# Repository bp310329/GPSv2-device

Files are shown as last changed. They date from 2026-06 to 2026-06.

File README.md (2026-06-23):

# GPSv2-device
Program of embedded device. This is project of GPS device with sipmle navigation. This device allows for real-time GPS tracking and uploading location data to data base via GSM network, and presentation of this data on the map on website. Second application is simple navigation through points placed on the map.
[WIP]

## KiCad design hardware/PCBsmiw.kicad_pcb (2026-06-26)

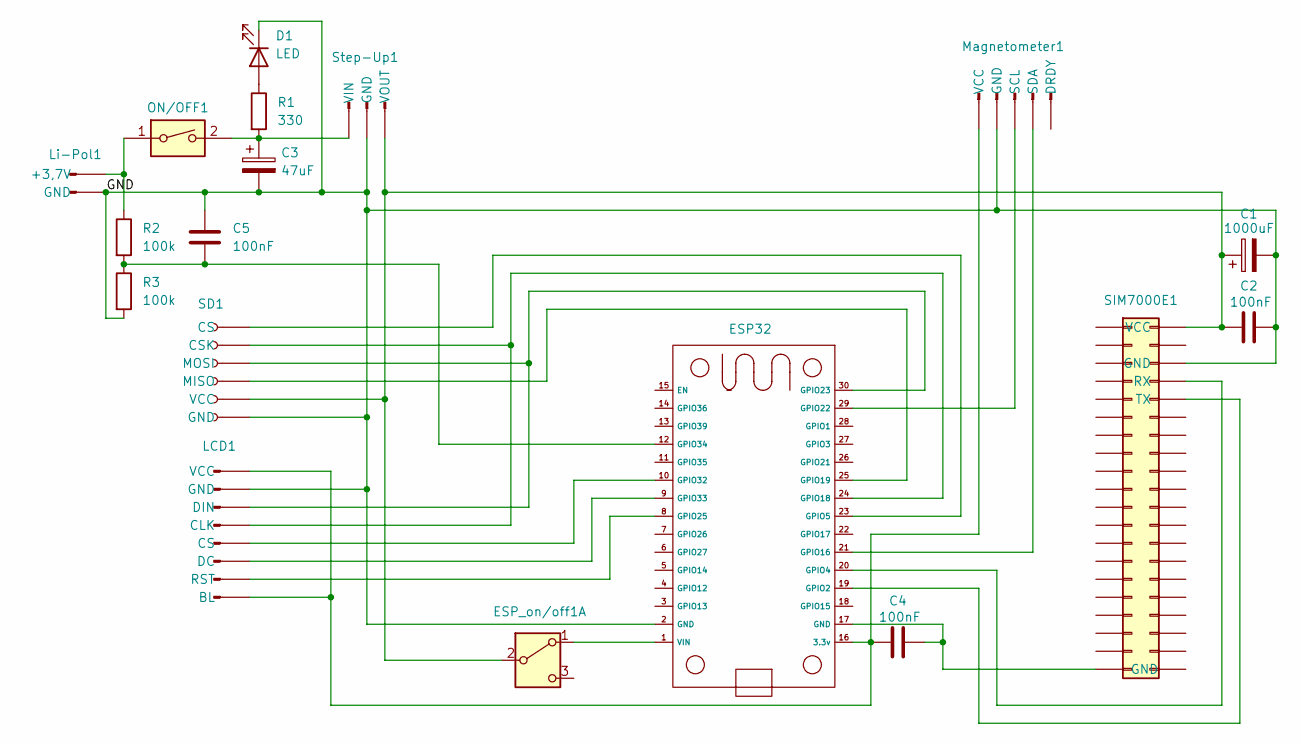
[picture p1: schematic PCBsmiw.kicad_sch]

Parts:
C1: 1000uF; CP_Radial_D10.0mm_P5.00mm
C2, C4, C5: 100nF; C_Disc_D3.8mm_W2.6mm_P2.50mm
C3: 47uF; CP_Radial_D5.0mm_P2.00mm
D1: LED; LED_D3.0mm
ESP32: ESP32_30pin
ESP_on/off1: SW_DPDT_x2; SW_CK_JS202011CQN_DPDT_Straight
LCD1: Conn_01x08_Pin; PinSocket_1x08_P2.54mm_Vertical
Li-Pol1: Conn_01x02_Pin; PinHeader_1x02_P2.54mm_Horizontal
Magnetometer1: Conn_01x05_Pin; PinHeader_1x05_P2.54mm_Vertical
ON/OFF1: SW_DIP_x01; SW_DIP_SPSTx01_Slide_9.78x4.72mm_W7.62mm_P2.54mm
R1: 330; R_Axial_DIN0207_L6.3mm_D2.5mm_P7.62mm_Horizontal
R2, R3: 100k; R_Axial_DIN0207_L6.3mm_D2.5mm_P7.62mm_Horizontal
SD1: Conn_01x06_Socket; PinSocket_1x06_P2.54mm_Horizontal
SIM7000E1: Conn_02x20_Odd_Even; PinHeader_2x20_P2.54mm_Vertical
Step-Up1: Conn_01x03_Pin; PinHeader_1x03_P2.54mm_Vertical

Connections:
/GND: C1.2, C2.2, C3.2, C5.1, D1.1 (K), ESP32.2 (GND), LCD1.2 (GND), Li-Pol1.2 (GND), Magnetometer1.2 (GND), R3.2, SD1.6 (GND), SIM7000E1.6 (GND), Step-Up1.2 (GND)
unnamed: C4.2, ESP32.17 (GND), SIM7000E1.39 (GND)
unnamed: D1.2 (A), R1.1
unnamed: C4.1, ESP32.16 (3.3v), LCD1.1 (VCC), LCD1.8 (BL), Magnetometer1.1 (VCC)
unnamed: ESP32.19 (GPIO2), SIM7000E1.10 (TX)
unnamed: ESP32.20 (GPIO4), SIM7000E1.8 (RX)
unnamed: ESP32.23 (GPIO5), SD1.1 (CS)
unnamed: ESP32.21 (GPIO16), Magnetometer1.4 (SDA)
unnamed: ESP32.24 (GPIO18), LCD1.4 (CLK), SD1.2 (CSK)
unnamed: ESP32.25 (GPIO19), SD1.4 (MISO)
unnamed: ESP32.29 (GPIO22), Magnetometer1.3 (SCL)
unnamed: ESP32.30 (GPIO23), LCD1.3 (DIN), SD1.3 (MOSI)
unnamed: ESP32.8 (GPIO25), LCD1.7 (RST)
unnamed: ESP32.10 (GPIO32), LCD1.5 (CS)
unnamed: ESP32.9 (GPIO33), LCD1.6 (DC)
unnamed: C5.2, ESP32.12 (GPIO34), R2.2, R3.1
unnamed: ESP32.1 (VIN), ESP_on/off1.1 (A)
unnamed: C1.1, C2.1, ESP_on/off1.2 (B), SD1.5 (VCC), SIM7000E1.2 (VCC), Step-Up1.1 (VOUT)
unnamed: Li-Pol1.1 (+3,7V), ON/OFF1.1, R2.1
unnamed: C3.1, ON/OFF1.2, R1.2, Step-Up1.3 (VIN)

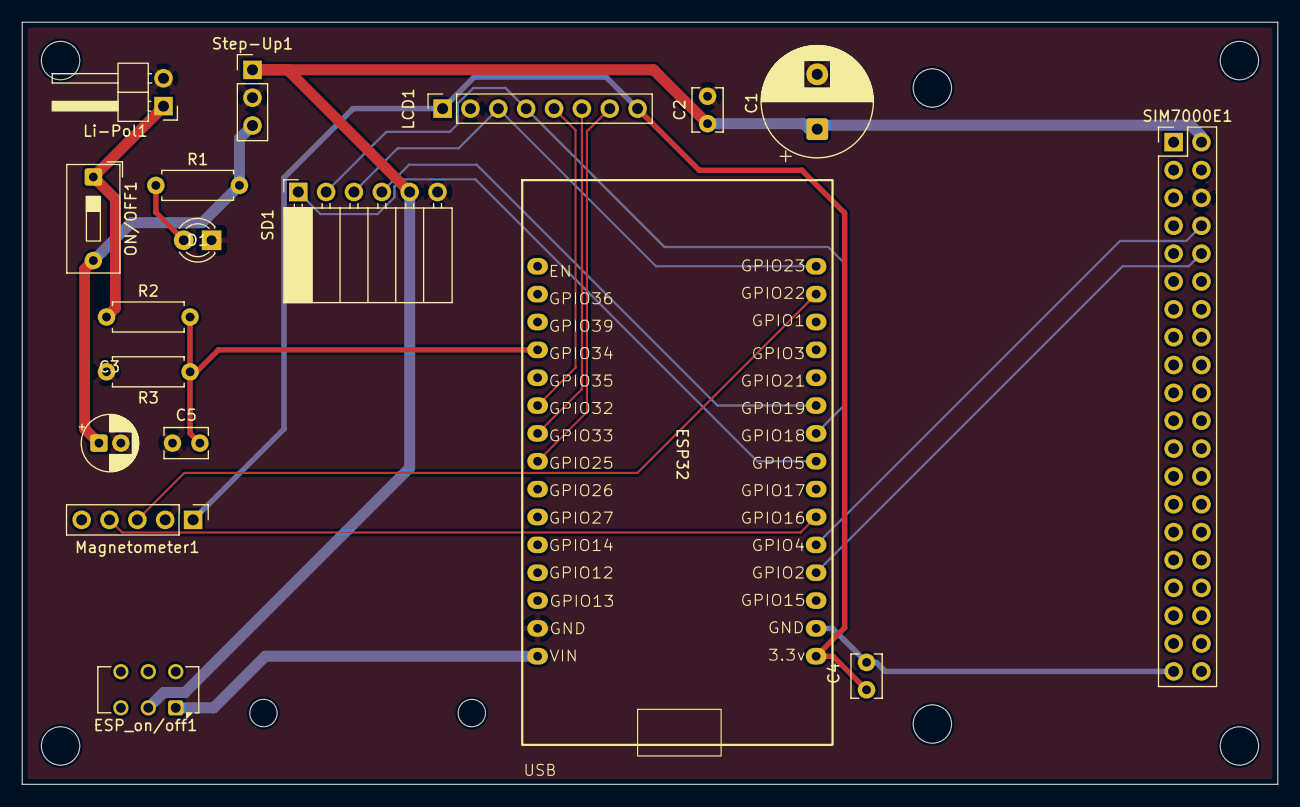
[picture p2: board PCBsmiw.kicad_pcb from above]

Board: 2 copper layers, 114.5 x 69.5 mm, 18 parts (0 on the bottom side), 20 nets.

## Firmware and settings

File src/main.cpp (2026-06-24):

#include <Arduino.h>
#include <Wire.h>
#include <SPI.h>
#include <Adafruit_GFX.h>
#include <Adafruit_ILI9341.h>
#include <Adafruit_QMC5883P.h>
#include <DFRobot_SIM7000.h>
#include <SdFat.h>
#include <ArduinoJson.h>
#include <math.h>

#define TFT_CS 32
#define TFT_DC 33
#define TFT_RST 25
#define MAG_SDA 16
#define MAG_SCL 22
#define SIM_TX 4
#define SIM_RX 2
#define SD_CS 5

struct Waypoint {
  float lat;
  float lon;
  bool visited;
};

Adafruit_ILI9341 tft = Adafruit_ILI9341(TFT_CS, TFT_DC, TFT_RST);
Adafruit_QMC5883P mag = Adafruit_QMC5883P();
DFRobot_SIM7000 sim7000(&Serial2);
SdFat SD;

Waypoint* waypoints = nullptr;
int currentTargetIndex = -1;

int posX = 10, posY = 10;
uint32_t loopTimer = 0, screenTimer = 0, transmisionTimer = 0;
bool APNStatus = false, connected = false;
byte mode = 0;
String currentTime, latitude, longitude;
float azimuth;
int gpsErrorCounter = 0;
float distanceToTarget = 0.0;
int arrowAngle = 0;

int savedCount = 0, totalWaypoints = 0;
int ok = 0, error = 0;

const int MAX_GPS_ERRORS = 6;
const char* DEVICE_ID = "tracker01";
const char* OFFLINE_FILE = "offlineData.txt";
const char* NAVI_FILE = "naviData.txt";
const char* SERVER = "http://frog03.mikr.us:21491/api/device/telemetry";
const char* MODE_URL = "http://frog03.mikr.us:21491/api/device/mode";
const char* WAYPOINTS_URL = "http://frog03.mikr.us:21491/api/device/pending-waypoints";

bool wait(uint32_t &lastTime, uint32_t interval);
void printLine(const String text, int &posX, int &posY, uint16_t color = ILI9341_WHITE, int textSize = 1);
void replaceLine(const String text, int &posX, int &posY, uint16_t color = ILI9341_WHITE, int textSize = 1);
void updateScreen();
bool initializeSIM7000();
bool initializeSIMCard();
bool initializeNetwork();
bool configureAPN();
bool initializeGPS();
bool waitForGPS();
String getTime();
void handleTransmission();
void saveToSD(String json);
void processOfflineDataBatch();
float calculateDistance(float lat1, float lon1, float lat2, float lon2);
float calculateBearing(float lat1, float lon1, float lat2, float lon2);
void findNextClosestWaypoint(float currentLat, float currentLon);
void drawNavigationArrow(int cx, int cy, int angle, uint16_t arrowColor);
float getAzimuth();

void setup() {
  Serial.begin(115200);
  Serial2.begin(115200, SERIAL_8N1, SIM_RX, SIM_TX);
  Wire.begin(MAG_SDA, MAG_SCL);

  Serial.println("MCU starting...");

  if (!mag.begin()) {
    Serial.println("Magnetometer has not been found!");
    while (1) {
      delay(10);
    }
  } else {
    Serial.println("Magnetometer OK");
  }

  mag.setMode(QMC5883P_MODE_NORMAL);
  mag.setODR(QMC5883P_ODR_50HZ);

  tft.begin();
  tft.setRotation(1);
  tft.fillScreen(ILI9341_BLACK);

  if (!SD.begin(SD_CS, SD_SCK_MHZ(4))) {
    Serial.println("SD Card Mount Failed!");
  } else {
    Serial.println("SD Card Initialized.");
  }
  SD.remove(OFFLINE_FILE);

  initializeSIM7000();
  initializeSIMCard();
  initializeNetwork();
  delay(5000);
  configureAPN();
  initializeGPS();

  delay(1000);
  posY = 10;
  waitForGPS();
  tft.fillScreen(ILI9341_BLACK);

  // =========================================================================
  // --- SPRAWDZANIE TRYBU I POBIERANIE WSPÓŁRZĘDNYCH ---
  // =========================================================================
  int setupX = 10, setupY = 10;

  printLine("Waiting for server...", setupX, setupY, ILI9341_WHITE, 2);
  
  String modeResponse = "";

  sim7000.httpGet(MODE_URL);
  
  while(Serial2.available()) Serial2.read();
  
  Serial2.print("AT+HTTPPARA=\"URL\",\"");
  Serial2.print(MODE_URL);
  Serial2.println("\"");
  delay(200);
  
  Serial2.println("AT+HTTPACTION=0");
  
  unsigned long start = millis();
  bool actionOk = false;
  while(millis() - start < 6000) {
    if(Serial2.available()) {
      String line = Serial2.readStringUntil('\n');
      if(line.indexOf("+HTTPACTION: 0,200") != -1) {
        actionOk = true;
        break;
      }
    }
    delay(10);
  }
  
  if(actionOk) {
    Serial2.println("AT+HTTPREAD");
    delay(500);
    while(Serial2.available()) {
      modeResponse += (char)Serial2.read();
    }
  }

  if (modeResponse.indexOf("\"mode\":\"planning\"") != -1) {
    mode = 1;
    replaceLine("MODE: NAVIGATION", setupX, setupY, ILI9341_YELLOW, 2);
    printLine("Downloading waypoints...", setupX, setupY, ILI9341_WHITE, 2);
    
    SD.remove(NAVI_FILE);
    FsFile naviFile = SD.open(NAVI_FILE, O_RDWR | O_CREAT | O_APPEND);
    
    if (!naviFile) {
      printLine("SD Write Error!", setupX, setupY, ILI9341_RED, 2);
      mode = 0;
      return;
    }

    bool morePointsAvailable = true;

    while (morePointsAvailable) {
      while(Serial2.available()) Serial2.read();
      
      Serial2.print("AT+HTTPPARA=\"URL\",\"");
      Serial2.print(WAYPOINTS_URL);
      Serial2.println("\"");
      delay(200);
      
      Serial2.println("AT+HTTPACTION=0");
      
      unsigned long startWp = millis();
      bool wpActionOk = false;
      
      while(millis() - startWp < 8000) {
        if(Serial2.available()) {
          String line = Serial2.readStringUntil('\n');
          
          if(line.indexOf("+HTTPACTION:") != -1) {
            if(line.indexOf("0,200") != -1) {
              wpActionOk = true;
            } else {
              Serial.print("MODEM RETURNED ERROR STATE: ");
              Serial.println(line);
            }
            break;
          }
        }
        delay(10);
      }
      
      if(!wpActionOk) {
        Serial.println("Pętla zatrzymana: Brak statusu HTTP 200.");
        morePointsAvailable = false;
        break;
      }
      
      Serial2.println("AT+HTTPREAD");
      
      String wpResponse = "";
      unsigned long lastCharTime = millis();
      while (millis() - lastCharTime < 1000) {
        while (Serial2.available()) {
          char c = (char)Serial2.read();
          wpResponse += c;
          lastCharTime = millis();
        }
        delay(5);
      }
      
      int pointsIdx = wpResponse.indexOf("\"points\":[");
      if (pointsIdx != -1) {
        pointsIdx += 10;
        int batchSaved = 0;
        
        while (true) {
          int latIndex = wpResponse.indexOf("\"lat\":", pointsIdx);
          if (latIndex == -1) break;
          int latEnd = wpResponse.indexOf(",", latIndex);
          String latVal = wpResponse.substring(latIndex + 6, latEnd);
          
          int lngIndex = wpResponse.indexOf("\"lng\":", latEnd);
          if (lngIndex == -1) break;
          int lngEnd = wpResponse.indexOf("}", lngIndex);
          String lngVal = wpResponse.substring(lngIndex + 6, lngEnd);
          
          naviFile.println(latVal + "," + lngVal);
          savedCount++;
          batchSaved++;
          
          pointsIdx = lngEnd;
        }
        
        if (batchSaved == 0) {
          morePointsAvailable = false;
        }
        
        Serial.print("Pomyślnie zapisano partię ");
        Serial.print(batchSaved);
        Serial.println(" punktów.");
        
      } else {
          morePointsAvailable = false;
      }
      
      delay(1500); 
    }
    
    naviFile.close();
    
    if (savedCount > 0) {
      totalWaypoints = savedCount;

      printLine("Saved " + String(savedCount) + " points!", setupX, setupY, ILI9341_GREEN, 2);
      waypoints = new Waypoint[totalWaypoints];
      
      // 2. Otwarcie pliku ponownie - tym razem tylko DO ODCZYTU
      FsFile readFile = SD.open(NAVI_FILE, O_RDONLY);
      if (readFile) {
        int idx = 0;
        
        while (readFile.available() && idx < totalWaypoints) {
          String line = readFile.readStringUntil('\n');
          line.trim();
          
          int commaIdx = line.indexOf(',');
          if (commaIdx != -1) {
            String latStr = line.substring(0, commaIdx);
            String lonStr = line.substring(commaIdx + 1);
            
            waypoints[idx].lat = latStr.toFloat();
            waypoints[idx].lon = lonStr.toFloat();
            waypoints[idx].visited = false;
            
            idx++;
          }
        }
        readFile.close();
        
        Serial.print("[NAVI] Pomyślnie załadowano do RAM: ");
        Serial.print(idx);
        Serial.println(" punktów trasy.");
      } else {
        Serial.println("[CRITICAL] Nie udało się otworzyć pliku nawigacji do odczytu!");
        mode = 0;
      }
      
    } else {
      printLine("No active route found.", setupX, setupY, ILI9341_WHITE, 2);
      mode = 0;
    }
    delay(2000);
    
  } else {
    mode = 0;
  }

  tft.fillScreen(ILI9341_BLACK);
}

void loop() {
  switch (mode) {
    case 0:
      if (wait(loopTimer, 500)) {
        bool gotPosition = sim7000.getPosition();
        
        if (gotPosition) {
          latitude = sim7000.getLatitude();
          longitude = sim7000.getLongitude();
        } else {
          gpsErrorCounter++;
          
          if (gpsErrorCounter >= MAX_GPS_ERRORS) {
            waitForGPS();
            gpsErrorCounter = 0;
          }
        }
      }

      if (wait(screenTimer, 500)) {
        azimuth = getAzimuth();

        arrowAngle = (int)(round(azimuth / 15.0) * 15.0);
        if (arrowAngle >= 360) arrowAngle -= 360;
        updateScreen();
      }

      if (wait(transmisionTimer, 10000)) {
        handleTransmission();
      }
      
      break;

    case 1:
      if (wait(loopTimer, 500)) {
        bool gotPosition = sim7000.getPosition();
        
        if (gotPosition) {
          latitude = sim7000.getLatitude();
          longitude = sim7000.getLongitude();

          float tempLat = latitude.toFloat();
          float tempLon = longitude.toFloat();
          azimuth = getAzimuth();

          if (currentTargetIndex == -1) {
            findNextClosestWaypoint(tempLat, tempLon);
          }

          if (currentTargetIndex != -1) {
            distanceToTarget = calculateDistance(tempLat, tempLon, waypoints[currentTargetIndex].lat, waypoints[currentTargetIndex].lon);

            if (distanceToTarget <= 25.0) {
              Serial.print("PUNKT ZDOBYTY! Indeks: "); Serial.println(currentTargetIndex);
              waypoints[currentTargetIndex].visited = true;
              
              findNextClosestWaypoint(tempLat, tempLon);
            }

            if (currentTargetIndex != -1) {
              float bearingToTarget = calculateBearing(tempLat, tempLon, waypoints[currentTargetIndex].lat, waypoints[currentTargetIndex].lon);
              
              float relativeAngle = bearingToTarget - azimuth;
              if (relativeAngle < 0) relativeAngle += 360.0;

              arrowAngle = (int)(round(relativeAngle / 15.0) * 15.0);
              if (arrowAngle >= 360) arrowAngle -= 360;
            }
          } else {
            Serial.println("Wszystkie punkty zostały zdobyte! Koniec podróży.");
            arrowAngle = 0;
            distanceToTarget = 0.0;
            mode = 0;
          }

        } else {
          gpsErrorCounter++;
          if (gpsErrorCounter >= MAX_GPS_ERRORS) {
            waitForGPS();
            gpsErrorCounter = 0;
          }
        }
      }

      if (wait(screenTimer, 500)) {
        updateScreen();
      }

      break;
  }
}

bool wait(uint32_t &lastTime, uint32_t interval) {
  uint32_t current = millis();
  if (current - lastTime >= interval) {
    lastTime = current;
    return true;
  }
  return false;
}

void printLine(const String text, int &posX, int &posY, uint16_t color, int textSize) {
  tft.setCursor(posX, posY);
  tft.setTextColor(color);
  tft.setTextSize(textSize);
  tft.fillRect(posX, posY, 120, textSize * 10, ILI9341_BLACK);
  tft.println(text);
  posY += textSize * 10;
}

void replaceLine(const String text, int &posX, int &posY, uint16_t color, int textSize) {
  tft.fillRect(posX, posY - textSize * 10, tft.width() - posX * 2, textSize * 10, ILI9341_BLACK);
  int originalPosY = posY - textSize * 10;
  printLine(text, posX, originalPosY, color, textSize);
}

void updateScreen() {
  posY = 10;

  if (mode == 0) {
    printLine("MODE: TRACKER", posX, posY, ILI9341_YELLOW, 2);
  } else if (mode == 1) {
    printLine("MODE: NAVIGATION", posX, posY, ILI9341_YELLOW, 2);
  }

  if (connected) {
    printLine("ONLINE", posX, posY, ILI9341_GREEN, 2);
  } else {
    printLine("OFFLINE", posX, posY, ILI9341_RED, 2);
  }
  printLine(latitude, posX, posY, ILI9341_WHITE, 2);
  printLine(longitude, posX, posY, ILI9341_WHITE, 2);
  printLine(String(azimuth), posX, posY, ILI9341_WHITE, 2);

  if (mode == 0) {
    printLine(String(ok) + "/" + String(error), posX, posY, ILI9341_WHITE, 2);
  } else if (mode == 1) {
    printLine("Ang: " + String(arrowAngle), posX, posY, ILI9341_WHITE, 2);
  }

  drawNavigationArrow(230, 120, arrowAngle, ILI9341_RED);

  posY = 222;
  printLine(currentTime, posX, posY, ILI9341_WHITE, 1);
}

bool initializeSIM7000() {
  printLine("Initializing SIM7000...", posX, posY, ILI9341_WHITE, 2);

  if (sim7000.isON()) {
    printLine("OK", posX, posY, ILI9341_GREEN, 2);
    return true;
  } else {
    printLine("ERROR", posX, posY, ILI9341_RED, 2);

    while (!sim7000.isON()) {
      delay(500);
    }

    replaceLine("OK", posX, posY, ILI9341_GREEN, 2);
    return true;
  }
}

bool initializeSIMCard() {
  printLine("Checking SIM card...", posX, posY, ILI9341_WHITE, 2);

  if (sim7000.checkSIMStatus()) {
    printLine("OK", posX, posY, ILI9341_GREEN, 2);
    return true;
  } else {
    printLine("ERROR", posX, posY, ILI9341_RED, 2);

    while (!sim7000.checkSIMStatus()) {
      delay(500);
    }

    replaceLine("OK", posX, posY, ILI9341_GREEN, 2);
    return true;
  }
}

bool initializeNetwork() {
  printLine("Setting network mode...", posX, posY, ILI9341_WHITE, 2);

  if (sim7000.setNetMode(sim7000.eGPRS)) {
    printLine("OK", posX, posY, ILI9341_GREEN, 2);
    return true;
  } else {
    printLine("ERROR", posX, posY, ILI9341_RED, 2);

    while (!sim7000.setNetMode(sim7000.eGPRS)) {
      delay(500);
    }

    replaceLine("OK", posX, posY, ILI9341_GREEN, 2);
    return true;
  }
}

bool configureAPN() {
  printLine("Configuring APN...", posX, posY, ILI9341_WHITE, 2);

  if (sim7000.httpInit(sim7000.eGPRS, APNStatus)) {
    printLine("OK", posX, posY, ILI9341_GREEN, 2);
    return true;
  } else {
    printLine("ERROR", posX, posY, ILI9341_RED, 2);

    while (!sim7000.httpInit(sim7000.eGPRS, APNStatus)) {
      delay(500);
    }

    replaceLine("OK", posX, posY, ILI9341_GREEN, 2);
    return true;
  }
}

bool initializeGPS() {
  printLine("Initializing GPS...", posX, posY, ILI9341_WHITE, 2);

  if (sim7000.initPos()) {
    printLine("OK", posX, posY, ILI9341_GREEN, 2);
    return true;
  } else {
    printLine("ERROR", posX, posY, ILI9341_RED, 2);

    while (!sim7000.initPos()) {
      delay(500);
    }

    replaceLine("OK", posX, posY, ILI9341_GREEN, 2);
    return true;
  }
}

bool waitForGPS() {
  posY = 10;
  tft.fillScreen(ILI9341_BLACK);
  printLine("Fixing GPS...", posX, posY, ILI9341_WHITE, 2);

  while (1) {
    bool gotPos = sim7000.getPosition();

    if (gotPos) {
      printLine("GPS fixed!", posX, posY, ILI9341_GREEN, 2);
      delay(1000);
      return true;
    }
    delay(300);
  }
  return false;
}

String getTime() {
  Serial2.println("AT+CGNSINF");
  unsigned long start = millis();
  String response = "";

  while (millis() - start < 1000) {
    if (Serial2.available()) {
      response += (char)Serial2.read();
    }
    delay(10);
  }

  int fixIdx = response.indexOf("+CGNSINF: 1,1");
  if (fixIdx != -1) {
    int firstComma = response.indexOf(',', fixIdx);
    int secondComma = response.indexOf(',', firstComma + 1);
    int thirdComma = response.indexOf(',', secondComma + 1);

    String raw = response.substring(secondComma + 1, thirdComma);
    
    if (raw.length() >= 14) {
      String y = raw.substring(0, 4);
      String m = raw.substring(4, 6);
      String d = raw.substring(6, 8);
      String hh = raw.substring(8, 10);
      String mm = raw.substring(10, 12);
      String ss = raw.substring(12, 14);

      return y + "-" + m + "-" + d + " " + hh + ":" + mm + ":" + ss;
    }
  }
  return "";
}

void handleTransmission() {
  float tempLat = latitude.toFloat();
  float tempLon = longitude.toFloat();


  if (tempLat == 0.0 || tempLon == 0.0) {
    Serial.println("BŁĄD WALIDACJI: Współrzędne to (0.0, 0.0) - brak poprawnego fixu GPS. Anulowano.");
    return; 
  }

  // B. Sprawdzenie fizycznych granic geograficznych (Ziemia)
  if (tempLat < -90.0 || tempLat > 90.0 || tempLon < -180.0 || tempLon > 180.0) {
    Serial.println("KRYTYCZNY BŁĄD: Współrzędne GPS poza zakresem fizycznym globu! Dane odrzucone.");
    return;
  }

  delay(100);

  StaticJsonDocument<256> doc;

  doc["device_id"] = String(DEVICE_ID);
  doc["timestamp"] = "";
  doc["lat"] = tempLat;
  doc["lon"] = tempLon;

  String json;
  serializeJson(doc, json);

  Serial.println("Wygenerowano poprawny i zweryfikowany pakiet telemetryczny:");
  Serial.println(json);

  bool success = sim7000.httpPost(SERVER, json);

  if (success) {
    connected = true;
    ok++;
    processOfflineDataBatch();
  } else {
    connected = false;
    error++;
    saveToSD(json);
  }
}

void saveToSD(String json) {
  FsFile file = SD.open(OFFLINE_FILE, O_RDWR | O_CREAT | O_APPEND);
  if (file) {
    file.println(json);
    file.close();
    Serial.println("Data appended to SD");
  } else {
    Serial.println("Failed to open SD for writing");
  }
}

void processOfflineDataBatch() {
  if (!SD.exists(OFFLINE_FILE)) {
    return;
  }
  FsFile file = SD.open(OFFLINE_FILE, O_READ);
  FsFile newFile = SD.open("temp.txt", O_RDWR | O_CREAT | O_TRUNC);

  if (!file || !newFile) {
    if (file) file.close();
    if (newFile) newFile.close();
    return;
  }

  Serial.println("Processing offline buffer in batches...");
  const int BATCH_SIZE = 10;
  bool batchFailed = false;

  while (true) {
    String linesCache[BATCH_SIZE];
    int linesRead = 0;

    while (file.available() && linesRead < BATCH_SIZE) {
      String jsonLine = file.readStringUntil('\n');
      jsonLine.trim();
      if (jsonLine.length() > 0) {
        linesCache[linesRead++] = jsonLine;
      }
    }
    bool hasMore = file.available();

    if (linesRead == 0) break;

    if (!batchFailed) {
      String batchJson = "[";
      for (int i = 0; i < linesRead; i++) {
        if (i > 0) batchJson += ",";
        batchJson += linesCache[i];
      }
      batchJson += "]";

      bool success = sim7000.httpPost(SERVER, batchJson);

      if (!success) {
        batchFailed = true;
        Serial.println("Batch send FAILED!");
      } else {
        Serial.println("Batch sent successfully!");
        delay(1500);
      }
    }

    if (batchFailed) {
      for (int i = 0; i < linesRead; i++) {
        newFile.println(linesCache[i]);
      }
    }
    delay(100);

    if (!hasMore) break;
  }

  file.close();
  newFile.close();

  SD.remove(OFFLINE_FILE);
  FsFile checkTemp = SD.open("temp.txt", O_READ);
  if (checkTemp && checkTemp.size() > 0) {
    checkTemp.close();
    SD.rename("temp.txt", OFFLINE_FILE);
  } else {
    if (checkTemp) checkTemp.close();
    SD.remove("temp.txt");
  }
}

float calculateDistance(float lat1, float lon1, float lat2, float lon2) {
  float dLat = (lat2 - lat1) * PI / 180.0;
  float dLon = (lon2 - lon1) * PI / 180.0;
  
  float a = sin(dLat / 2) * sin(dLat / 2) +
            cos(lat1 * PI / 180.0) * cos(lat2 * PI / 180.0) *
            sin(dLon / 2) * sin(dLon / 2);
  float c = 2 * atan2(sqrt(a), sqrt(1 - a));
  return 6371000.0 * c;
}

float calculateBearing(float lat1, float lon1, float lat2, float lon2) {
  float lat1Rad = lat1 * PI / 180.0;
  float lat2Rad = lat2 * PI / 180.0;
  float dLon = (lon2 - lon1) * PI / 180.0;

  float y = sin(dLon) * cos(lat2Rad);
  float x = cos(lat1Rad) * sin(lat2Rad) - sin(lat1Rad) * cos(lat2Rad) * cos(dLon);
  
  float bearing = atan2(y, x) * 180.0 / PI;
  if (bearing < 0) bearing += 360.0;
  return bearing;
}

void findNextClosestWaypoint(float currentLat, float currentLon) {
  float minDistance = 9999999.0;
  int closestIdx = -1;

  for (int i = 0; i < totalWaypoints; i++) {
    if (!waypoints[i].visited) {
      float dist = calculateDistance(currentLat, currentLon, waypoints[i].lat, waypoints[i].lon);
      if (dist < minDistance) {
        minDistance = dist;
        closestIdx = i;
      }
    }
  }
  currentTargetIndex = closestIdx;
}

void drawNavigationArrow(int cx, int cy, int angle, uint16_t arrowColor) {
  static int lastAngle = -1;

  if (angle == lastAngle) return;

  tft.fillRect(cx - 70, cy - 70, 140, 140, ILI9341_BLACK);
  lastAngle = angle;

  tft.drawCircle(cx, cy, 68, ILI9341_DARKGREEN);
  tft.drawFastVLine(cx, cy - 68, 6, ILI9341_WHITE);
  tft.drawFastVLine(cx, cy + 62, 6, ILI9341_WHITE);
  tft.drawFastHLine(cx - 68, cy, 6, ILI9341_WHITE);
  tft.drawFastHLine(cx + 62, cy, 6, ILI9341_WHITE);

  float radMain   = angle * PI / 180.0;
  float radLeft   = (angle + 145) * PI / 180.0;
  float radRight  = (angle - 145) * PI / 180.0;
  float radIndent = (angle + 180) * PI / 180.0;

  int xTip    = cx + (int)(60 * sin(radMain));
  int yTip    = cy - (int)(60 * cos(radMain));

  int xLeft   = cx + (int)(45 * sin(radLeft));
  int yLeft   = cy - (int)(45 * cos(radLeft));

  int xRight  = cx + (int)(45 * sin(radRight));
  int yRight  = cy - (int)(45 * cos(radRight));

  int xIndent = cx + (int)(20 * sin(radIndent));
  int yIndent = cy - (int)(20 * cos(radIndent));
  
  tft.fillTriangle(xTip, yTip, xLeft, yLeft, xIndent, yIndent, arrowColor);
  
  uint16_t darkColor = (arrowColor == ILI9341_RED) ? 0x9000 : ILI9341_DARKGREY;
  tft.fillTriangle(xTip, yTip, xRight, yRight, xIndent, yIndent, darkColor);

  tft.drawTriangle(xTip, yTip, xLeft, yLeft, xIndent, yIndent, ILI9341_WHITE);
  tft.drawTriangle(xTip, yTip, xRight, yRight, xIndent, yIndent, ILI9341_WHITE);
}
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
